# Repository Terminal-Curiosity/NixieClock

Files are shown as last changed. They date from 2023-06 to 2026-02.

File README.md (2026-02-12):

# Nixie Clock

A retro-style digital clock built with nixie tubes and an ESP32 microcontroller, custom built to fit into the scrap metal remains of an X-ray Tube.

## Features

- **Nixie Tube Display**: Classic nixie tube display showing time in HHMM format
- **2x Custom PCBs**: Designed to retrofit the X-ray Tube shell
- **RGB LED Backlight**: RGB LEDs behind each tube for added colour and dazzle
- **ESP32 Microcontroller**: Powered by an ESP32 Wroom32 microcontroller dev board
- **WiFi Time sync**: Daily time sync using wifi NTP to correct against clock drift and daylight savings
- **Cathode Protection**: daily nixie tube conditioning to prevent cathode poisoning

## Block Diagram

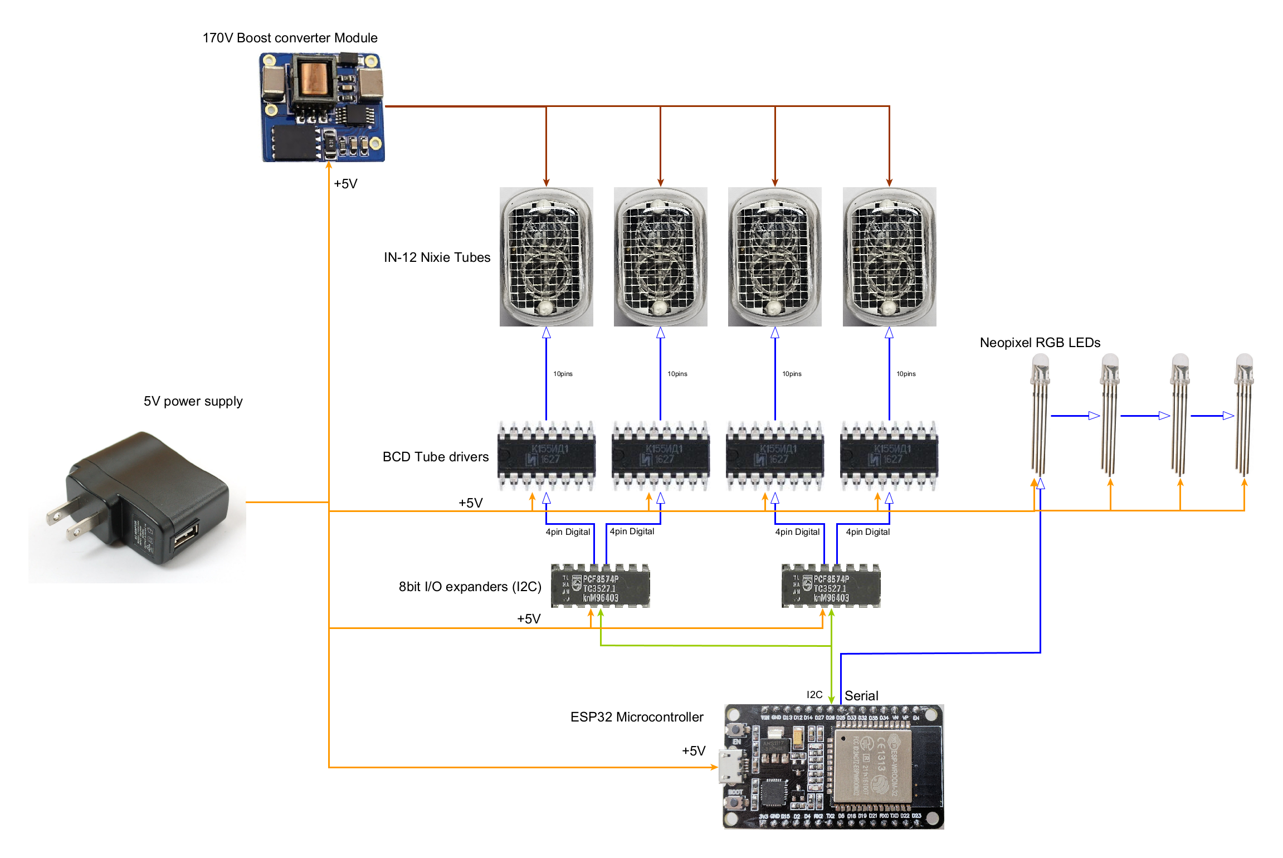
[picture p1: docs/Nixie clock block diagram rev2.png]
Nixie Clock Block Diagram


## Hardware

### Main Components

- **Microcontroller**: ESP32 Wroom32 DevKit-C
- **Nixie Tubes**: 4x IN-12 display
- **I/O Expansion**: 2x PCF8574 I2C I/O expanders
- **Decoders**: K155ID1 BCD-to-decimal decoders
- **Brightness Control**: Light Dependent Resistor (LDR)
- **Decoration LEDs**: 4x PL9823 RGB LEDs
- **High Voltage Supply**: NCH8200HV Nixie Power Booster Module

### Custom PCBs

The project includes Two custom PCB designs:

1. **NixieClock_ControlDaughterBoard**: Main control board with ESP32, HV Supply and LEDs
2. **NixieClock_NixieTubePanel**: Nixie tube display panel with decoder logic

### GPIO Pin Configuration

| Pin | Function |
|-----|---|
| 4 | SDA1 (I2C Bus 1) |
| 15  | SCL1 (I2C Bus 1) |
| 21  | SDA2 (I2C Bus 2) |
| 22  | SCL2 (I2C Bus 2) |
| 19  | INT2 (Interrupt, unused) |
| 32  | RGB LED (NeoPixel) |
| 23  | HV Enable (High Voltage supply) |
| 33  | LDR (Analog input) |

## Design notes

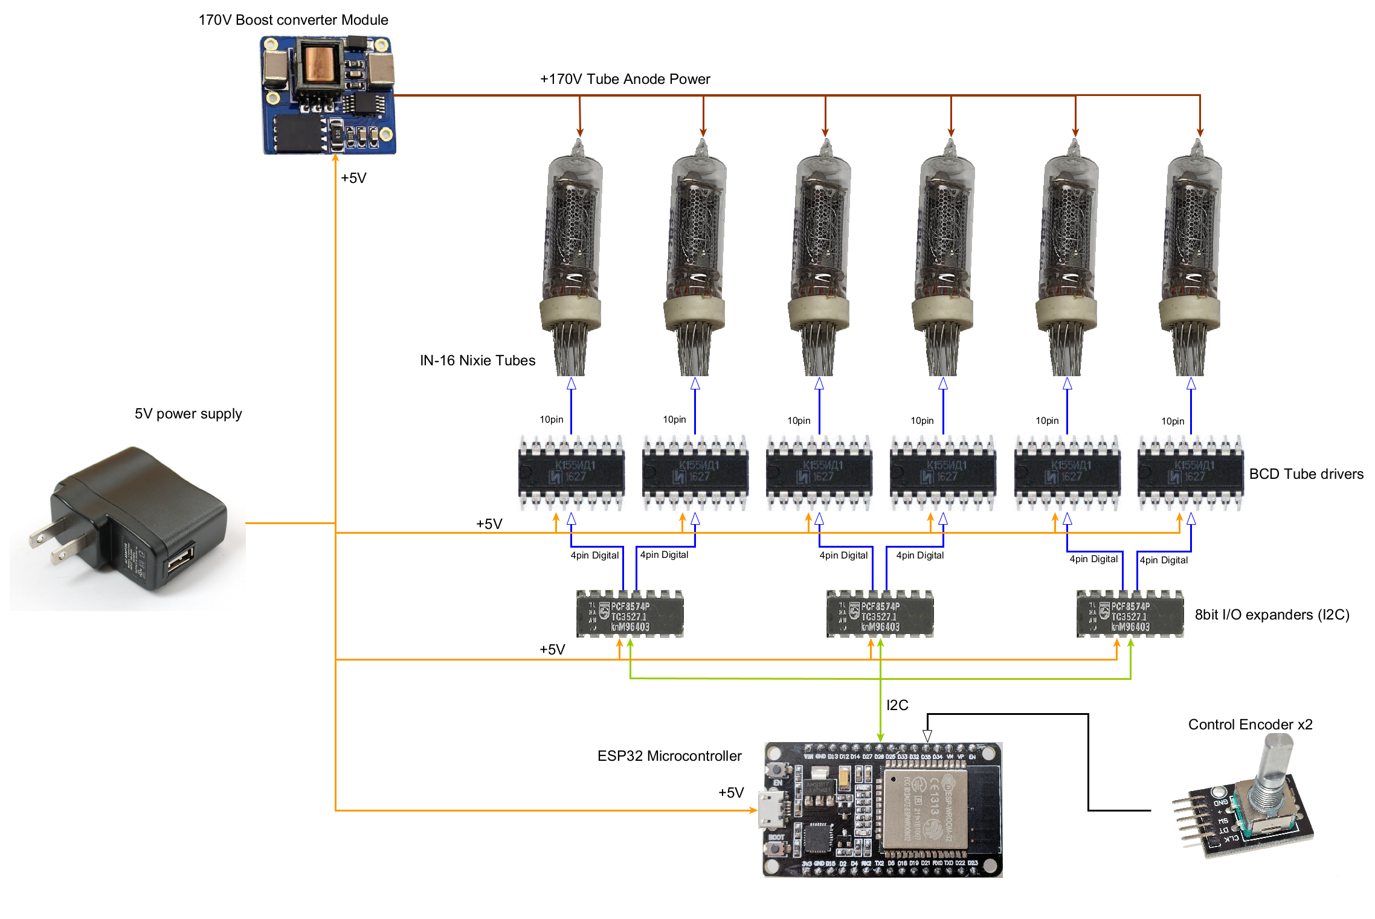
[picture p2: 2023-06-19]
docs/design/Nixie clock block diagram.png

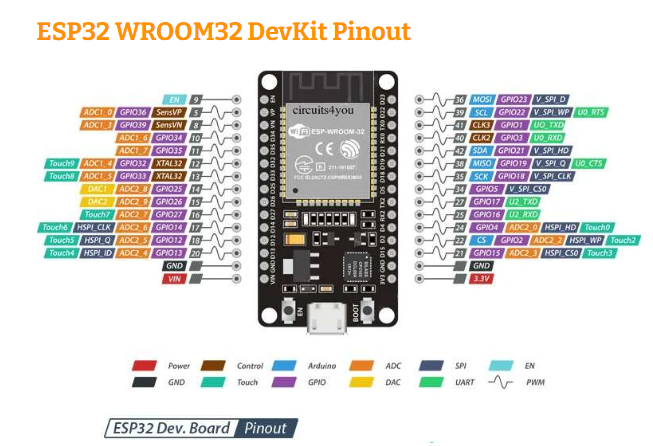
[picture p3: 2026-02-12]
docs/Datasheets/ESP32 pinout.png

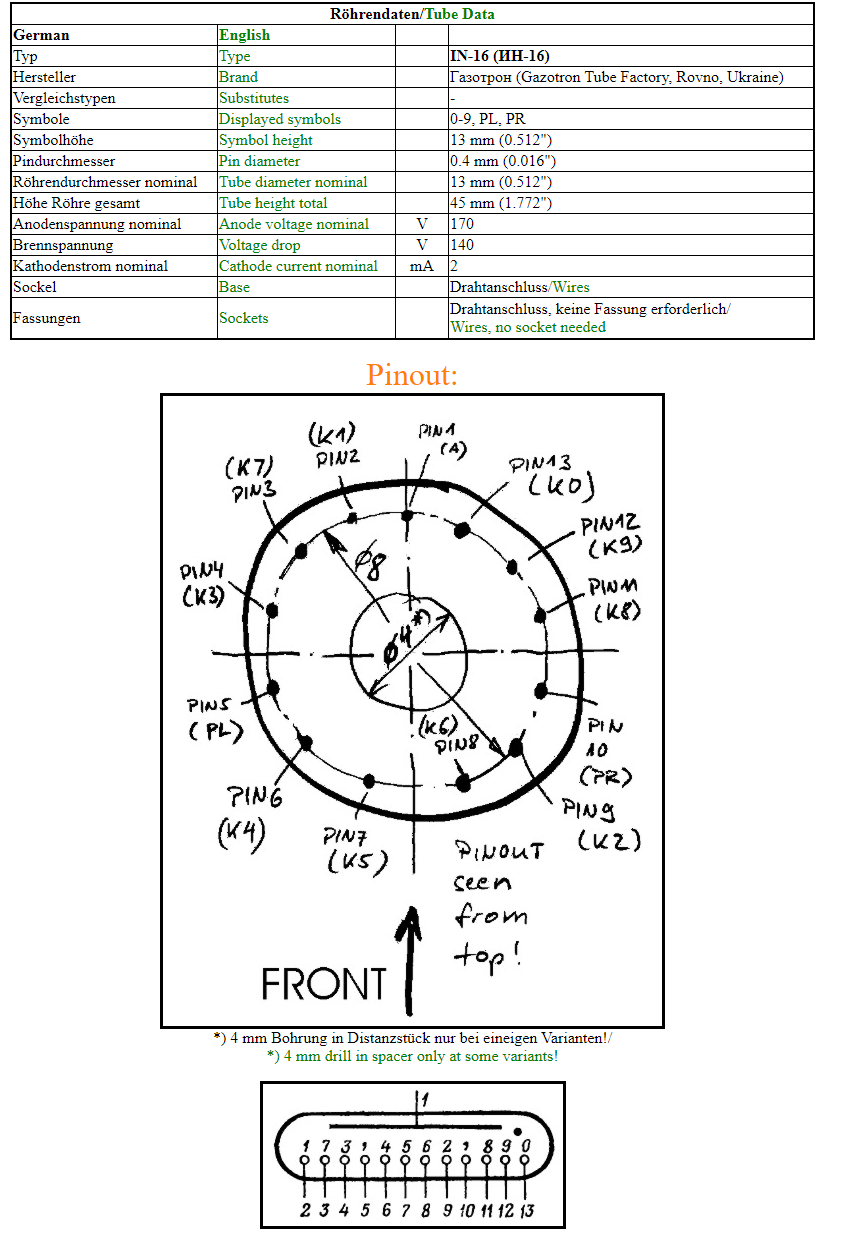
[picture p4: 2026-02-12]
docs/Datasheets/IN-16 Pinout and footprint.PNG

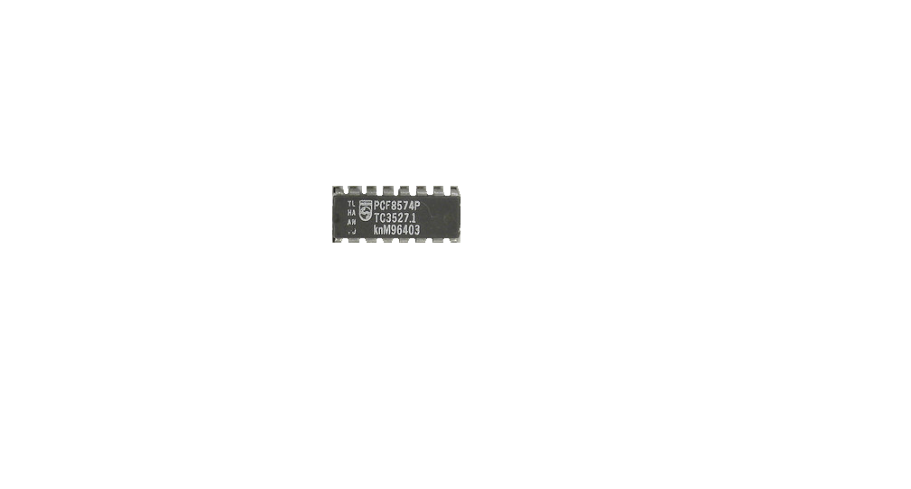
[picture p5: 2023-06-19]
docs/images/PCF8574 image.png

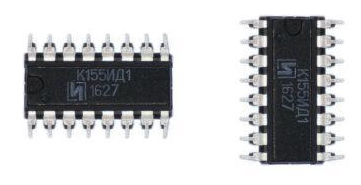
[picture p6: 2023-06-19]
docs/images/K155ND1 image.png

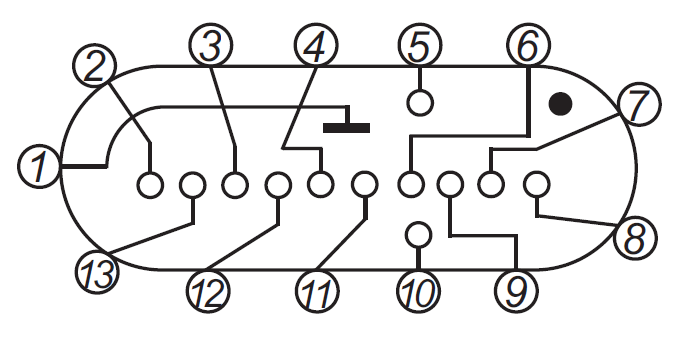
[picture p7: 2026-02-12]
docs/Datasheets/IN-16 Symbol.PNG

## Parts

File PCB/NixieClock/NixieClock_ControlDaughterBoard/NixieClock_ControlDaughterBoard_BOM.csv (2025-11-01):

Reference | Value | Description | Qty | Manufacturer | Manufacturer PN | Supplier
A1 | ASSY_NCH8200HV | NCH8200HV HV power supply 2.5-15VDC to 170V | 1 | Unknown | ASSY_NCH8200HV | Amazon
A2 | IC_ESP32-WROOM-32_DEVKIT | ESP32-WROOM-32 DEVKIT 30pin version | 1 | Espressif Systems | ESP32-WROOM-32_DEVKIT | Amazon
A3 | 4090 | ADAFRUIT USB C BREAKOUT BOARD | 1 | Adafruit | 4090 | Digikey
C1 | 470uF | CAP ALUM 470UF 20% 16V SMD | 1 | Nichicon | UWT1C471MNL1GS | Digikey
C2,C3 | 100nF | CAP CER 0.1UF 100V X7R 0805 | 2 | Samsung | CL21B104KCFNNNE | Digikey
D1,D2,D3,D4 | LED_IN-RGB-PL9823 | RGB LED Serial | 4 | Generic | PL9823 | Terminal Curiosity
F1 | 1.5A PTC | Resettable fuse, polymeric positive temperature coefficient | 1 | Littelfuse | NANOSMDC150F-2 | Digikey
J1,J2 | Conn_01x05 | CONN HEADER VERT 5POS 2.5MM | 2 | JST Sales America Inc. | B5B-XH-A | Digikey
J3,J4 | Conn_01x04 | CONN HDR 4POS 0.1 TIN PCB | 2 | Sullins Connector Solutions | PPTC041LFBN-RC | Digikey
Q1,Q2 | IRLML6244 | 6.3A Id, 20V Vds, 21mOhm Rds, N-Channel StrongIRFET Power MOSFET, SOT-23 | 2 | Infineon | IRLML6244TRPBF | Digikey
Q3 | IRLML6402 | -3.7A Id, -20V Vds, 65mOhm Rds, P-Channel HEXFET Power MOSFET, SOT-23 | 1 | Infineon | IRLML6402TRPBF | Digikey
R1,R2,R5,R6 | 4.7K | RES 4.7K OHM 5% 1/8W 0805 | 4 | Yageo | RC0805JR-074K7L | Digikey
R3,R9 | 470R | RES 470 OHM 1% 1/8W 0805 | 2 | Yageo | RC0805FR-07470RL | Digikey
R4,R7,R8,R15,R17 | 10k | RES 10K OHM 1% 1/8W 0805 | 5 | Yageo | RC0805FR-1310KL | Digikey
TP1 | 5V | PC TEST POINT | 1 | KOA Speer | RCUCTE | Digikey
TP2 | 3V3 | PC TEST POINT | 1 | KOA Speer | RCUCTE | Digikey
TP5,TP6 | 0V | PC TEST POINT | 2 | KOA Speer | RCUCTE | Digikey

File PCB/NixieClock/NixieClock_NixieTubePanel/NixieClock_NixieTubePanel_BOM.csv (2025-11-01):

Reference | Value | Description | Qty | Manufacturer | Manufacturer PN | Supplier
X1,X2,X3,X4,X5,X6 | 5230 | BATT CONTACT SOLID MULTIPLE SMD | 6 | Keystone Electronics | 122TR | Digikey
U5,U6 | PCF8574 | PCF8574 8BIT I2C PORT EXPANDER | 2 | Texas Instruments | PCF8574ADWR | Digikey
U1,U2,U3,U4 | K155ID1 | K155ID1 NIXIE TUBE DRIVER IC | 4 | Unknown | Unknown | eBay
R18 | 10K | Light Dependent Resistor 10K 150V | 1 | LDR Photoresistors | LDR07 | Unknown
R9,R10,R11,R16 | 18K | RES 18K OHM 5% 1/4W 1206 | 4 | YAGEO | RC1206JR-0718KL | Digikey
N1,N2,N3,N4 | TUBE_IN-12A_Nixie | IN-12A Nixie tube | 4 | Unknown | Unknown | eBay
J3,J4 | Conn_01x04_Pin | Generic connector, single row, 01x04, script generated | 2 | Wurth Elektronik | 61300411121 | Digikey
C5,C6,C7,C8,C9,C10 | 100nF | CAP CER 0.1UF 100V X7R 0805 | 6 | Samsung | CL21B104KCFNNNE | Digikey

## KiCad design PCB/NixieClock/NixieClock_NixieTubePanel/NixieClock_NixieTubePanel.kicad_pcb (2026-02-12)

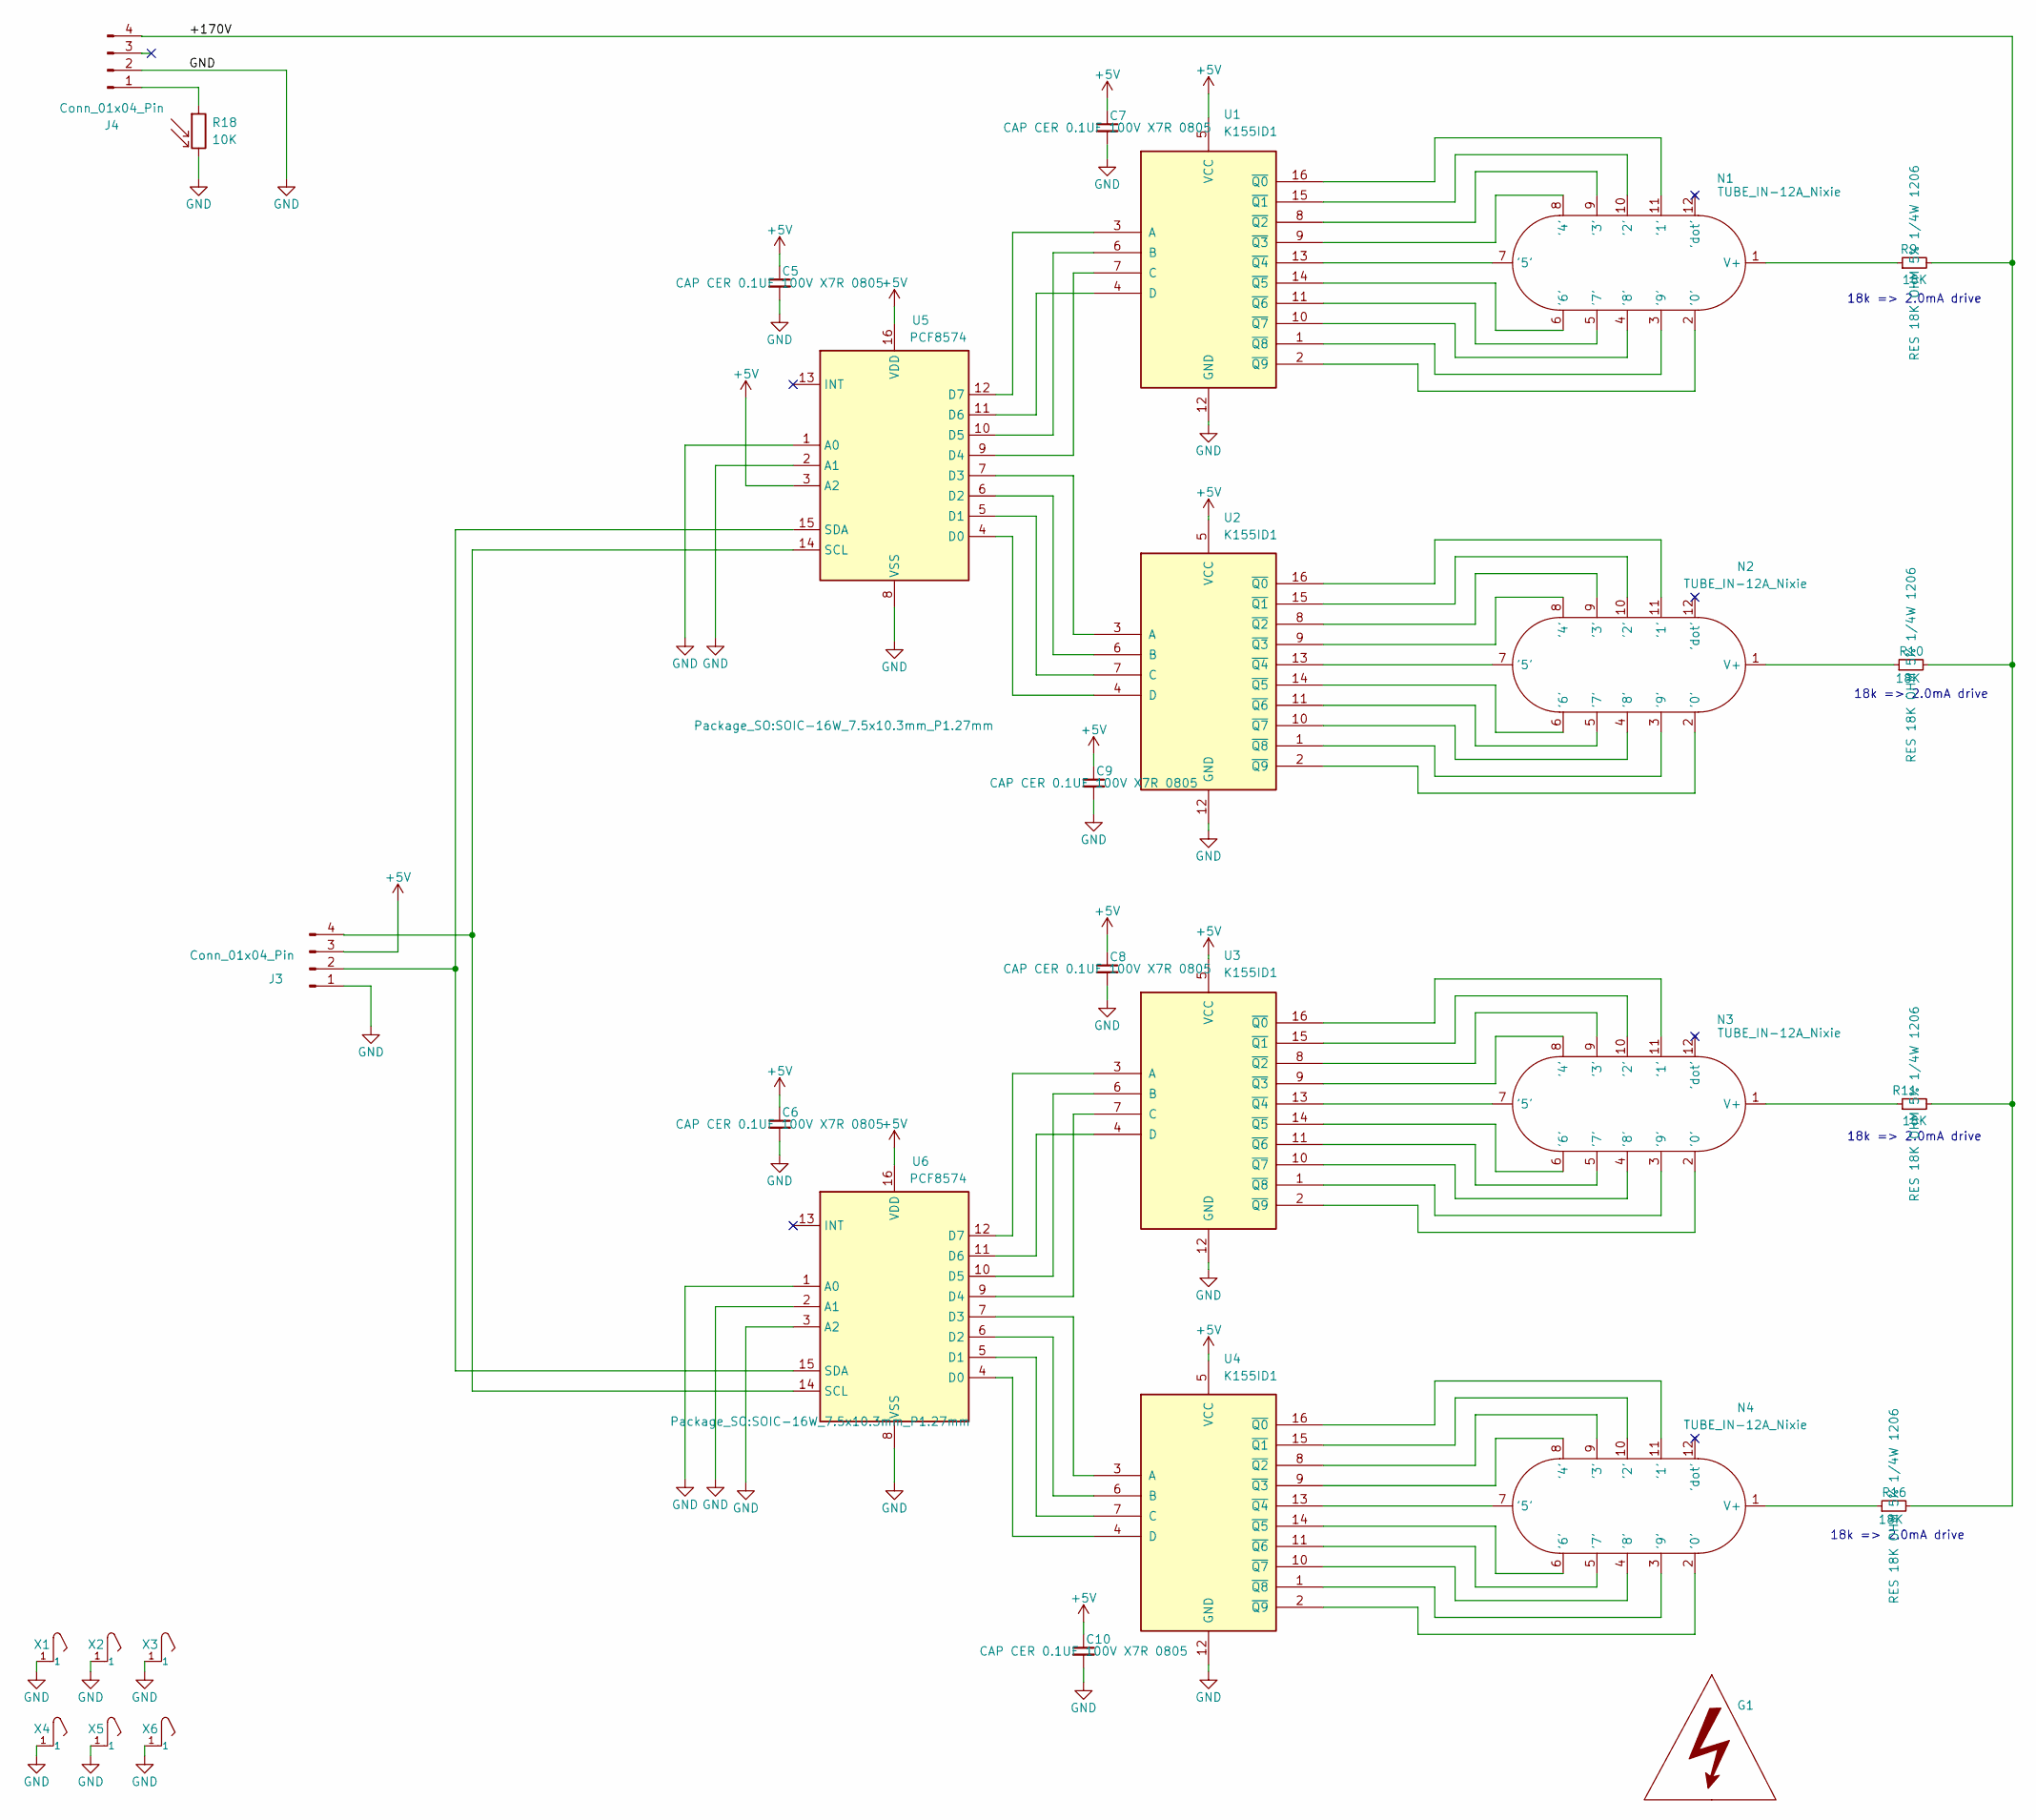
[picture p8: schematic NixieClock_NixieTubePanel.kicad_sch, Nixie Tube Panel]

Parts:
C5, C6, C7, C8, C9, C10: 100nF; C_0805_2012Metric_Pad1.18x1.45mm_HandSolder; Manufacturer PN CL21B104KCFNNNE
G1: LABEL_HVWarning
J3, J4: Conn_01x04_Pin; PinHeader_1x04_P2.54mm_Vertical; Manufacturer PN 61300411121
N1, N2, N3, N4: TUBE_IN-12A_Nixie; in-12_nixie-tube-socket; Manufacturer PN Unknown
R9, R10, R11, R16: 18K; R_1206_3216Metric_Pad1.30x1.75mm_HandSolder; Manufacturer PN RC1206JR-0718KL
R18: 10K; R_LDR_5.1x4.3mm_P3.4mm_Vertical; Manufacturer PN LDR07
U1, U2, U3, U4: K155ID1; DIP-16_W7.62mm; Manufacturer PN Unknown
U5, U6: PCF8574; SOIC-16W_7.5x10.3mm_P1.27mm; Manufacturer PN PCF8574ADWR
X1, X2, X3, X4, X5, X6: 5230; CONN-Batt-Spring-SMD-3.5mmX3.5mm; Manufacturer PN 122TR

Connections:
+5V: C5.1, C6.1, C7.1, C8.1, C9.1, C10.1, J3.3, U1.5 (VCC), U2.5 (VCC), U3.5 (VCC), U4.5 (VCC), U5.3 (A2), U5.16 (VDD), U6.16 (VDD)
/+170V: J4.4, R9.2, R10.2, R11.2, R16.2
GND: C5.2, C6.2, C7.2, C8.2, C9.2, C10.2, J3.1, J4.2, R18.2, U1.12 (GND), U2.12 (GND), U3.12 (GND), U4.12 (GND), U5.1 (A0), U5.2 (A1), U5.8 (VSS), U6.1 (A0), U6.2 (A1), U6.3 (A2), U6.8 (VSS), X1.1, X2.1, X3.1, X4.1, X5.1, X6.1
unnamed: J3.2, U5.15 (SDA), U6.15 (SDA)
unnamed: J3.4, U5.14 (SCL), U6.14 (SCL)
unnamed: J4.1, R18.1
unnamed: N1.2 ('0'), U1.2 (~Q9)
unnamed: N1.11 ('1'), U1.16 (~Q0)
unnamed: N1.10 ('2'), U1.15 (~Q1)
unnamed: N1.9 ('3'), U1.8 (~Q2)
unnamed: N1.8 ('4'), U1.9 (~Q3)
unnamed: N1.7 ('5'), U1.13 (~Q4)
unnamed: N1.6 ('6'), U1.14 (~Q5)
unnamed: N1.5 ('7'), U1.11 (~Q6)
unnamed: N1.4 ('8'), U1.10 (~Q7)
unnamed: N1.3 ('9'), U1.1 (~Q8)
unnamed: N1.1 (V+), R9.1
unnamed: N2.2 ('0'), U2.2 (~Q9)
unnamed: N2.11 ('1'), U2.16 (~Q0)
unnamed: N2.10 ('2'), U2.15 (~Q1)
unnamed: N2.9 ('3'), U2.8 (~Q2)
unnamed: N2.8 ('4'), U2.9 (~Q3)
unnamed: N2.7 ('5'), U2.13 (~Q4)
unnamed: N2.6 ('6'), U2.14 (~Q5)
unnamed: N2.5 ('7'), U2.11 (~Q6)
unnamed: N2.4 ('8'), U2.10 (~Q7)
unnamed: N2.3 ('9'), U2.1 (~Q8)
unnamed: N2.1 (V+), R10.1
unnamed: N3.2 ('0'), U3.2 (~Q9)
unnamed: N3.11 ('1'), U3.16 (~Q0)
unnamed: N3.10 ('2'), U3.15 (~Q1)
unnamed: N3.9 ('3'), U3.8 (~Q2)
unnamed: N3.8 ('4'), U3.9 (~Q3)
unnamed: N3.7 ('5'), U3.13 (~Q4)
unnamed: N3.6 ('6'), U3.14 (~Q5)
unnamed: N3.5 ('7'), U3.11 (~Q6)
unnamed: N3.4 ('8'), U3.10 (~Q7)
unnamed: N3.3 ('9'), U3.1 (~Q8)
unnamed: N3.1 (V+), R11.1
unnamed: N4.2 ('0'), U4.2 (~Q9)
unnamed: N4.11 ('1'), U4.16 (~Q0)
unnamed: N4.10 ('2'), U4.15 (~Q1)
unnamed: N4.9 ('3'), U4.8 (~Q2)
unnamed: N4.8 ('4'), U4.9 (~Q3)
unnamed: N4.7 ('5'), U4.13 (~Q4)
unnamed: N4.6 ('6'), U4.14 (~Q5)
unnamed: N4.5 ('7'), U4.11 (~Q6)
unnamed: N4.4 ('8'), U4.10 (~Q7)
unnamed: N4.3 ('9'), U4.1 (~Q8)
unnamed: N4.1 (V+), R16.1
unnamed: U1.3 (A), U5.12 (D7)
unnamed: U1.6 (B), U5.10 (D5)
unnamed: U1.7 (C), U5.9 (D4)
unnamed: U1.4 (D), U5.11 (D6)
unnamed: U2.3 (A), U5.7 (D3)
unnamed: U2.6 (B), U5.6 (D2)
unnamed: U2.7 (C), U5.5 (D1)
unnamed: U2.4 (D), U5.4 (D0)
unnamed: U3.3 (A), U6.12 (D7)
unnamed: U3.6 (B), U6.10 (D5)
unnamed: U3.7 (C), U6.9 (D4)
unnamed: U3.4 (D), U6.11 (D6)
unnamed: U4.3 (A), U6.7 (D3)
unnamed: U4.6 (B), U6.6 (D2)
unnamed: U4.7 (C), U6.5 (D1)
unnamed: U4.4 (D), U6.4 (D0)

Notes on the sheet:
18k => 2.0mA drive

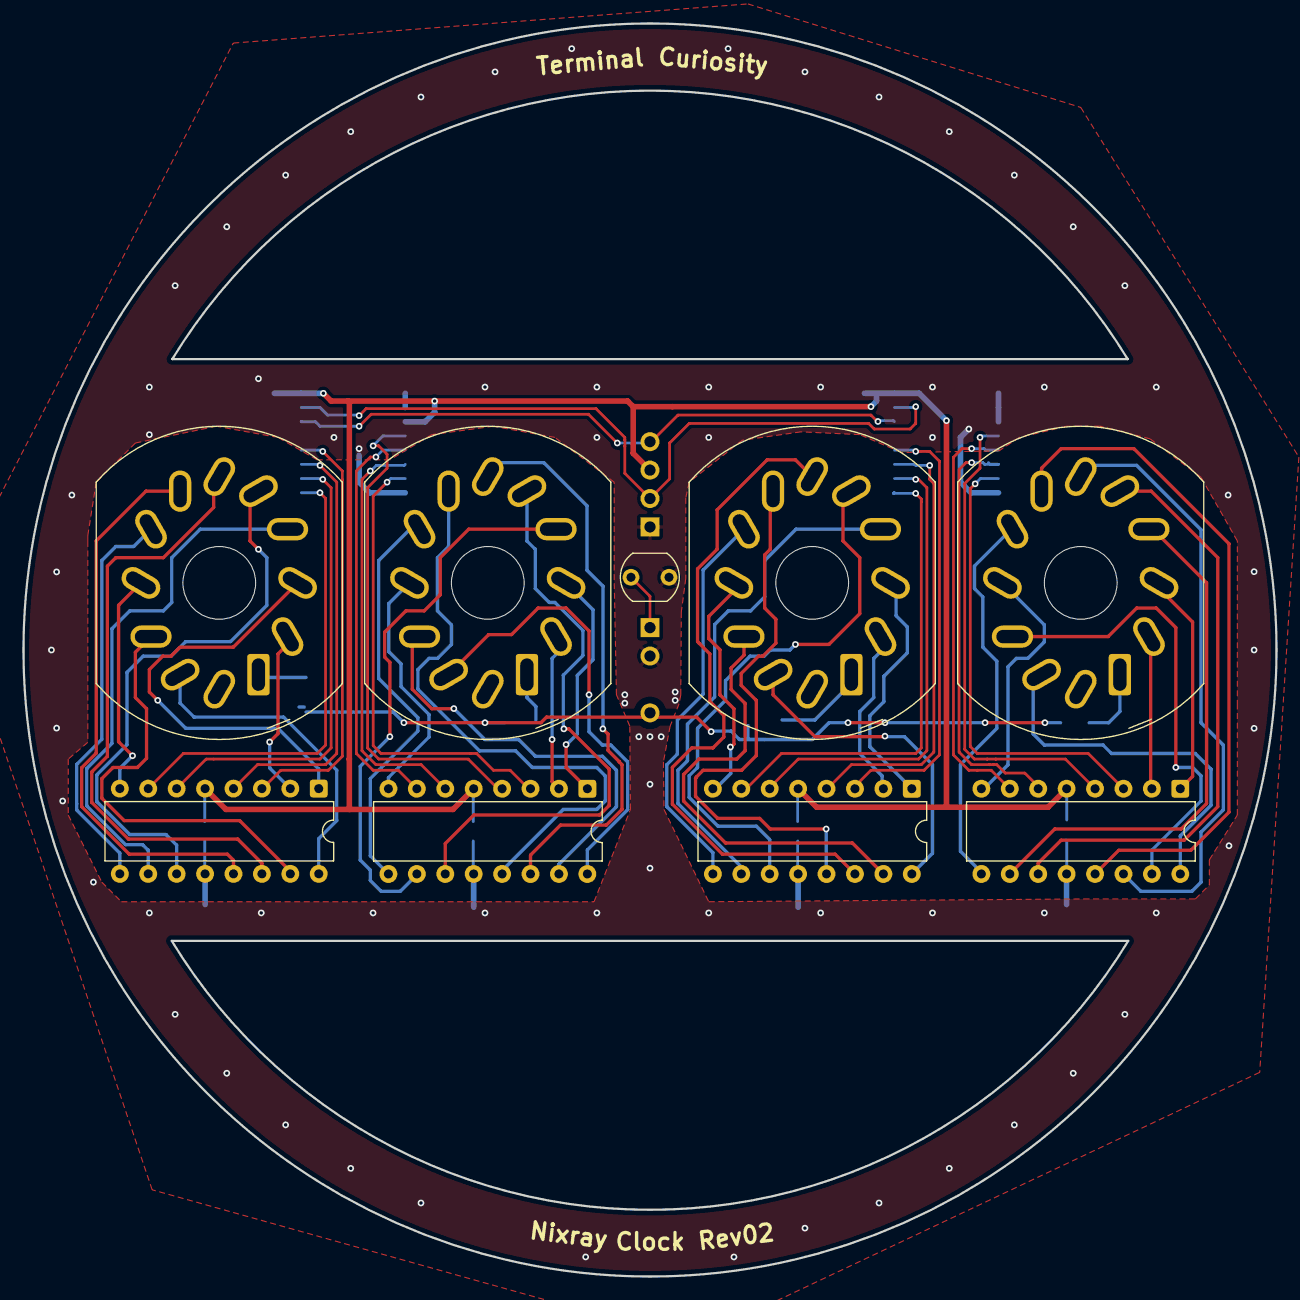
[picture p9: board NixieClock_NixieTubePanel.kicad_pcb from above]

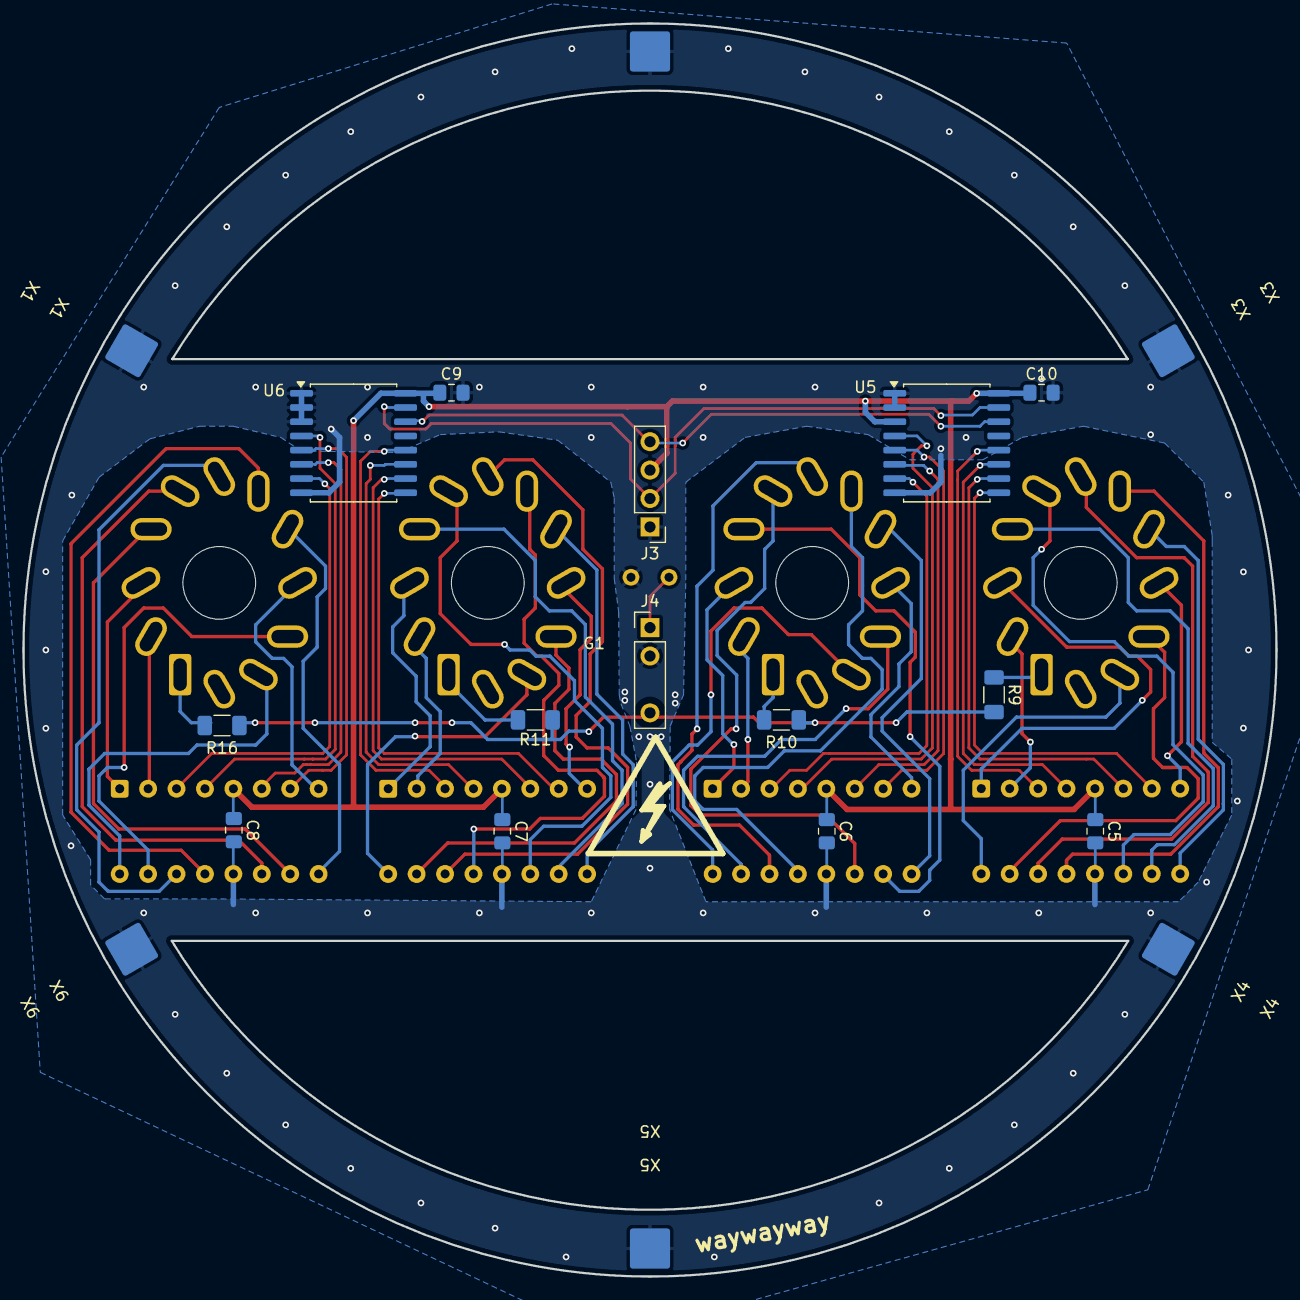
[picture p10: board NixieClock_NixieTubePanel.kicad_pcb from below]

Board: 2 copper layers, 112.0 x 112.0 mm, 30 parts (21 on the bottom side), 66 nets.

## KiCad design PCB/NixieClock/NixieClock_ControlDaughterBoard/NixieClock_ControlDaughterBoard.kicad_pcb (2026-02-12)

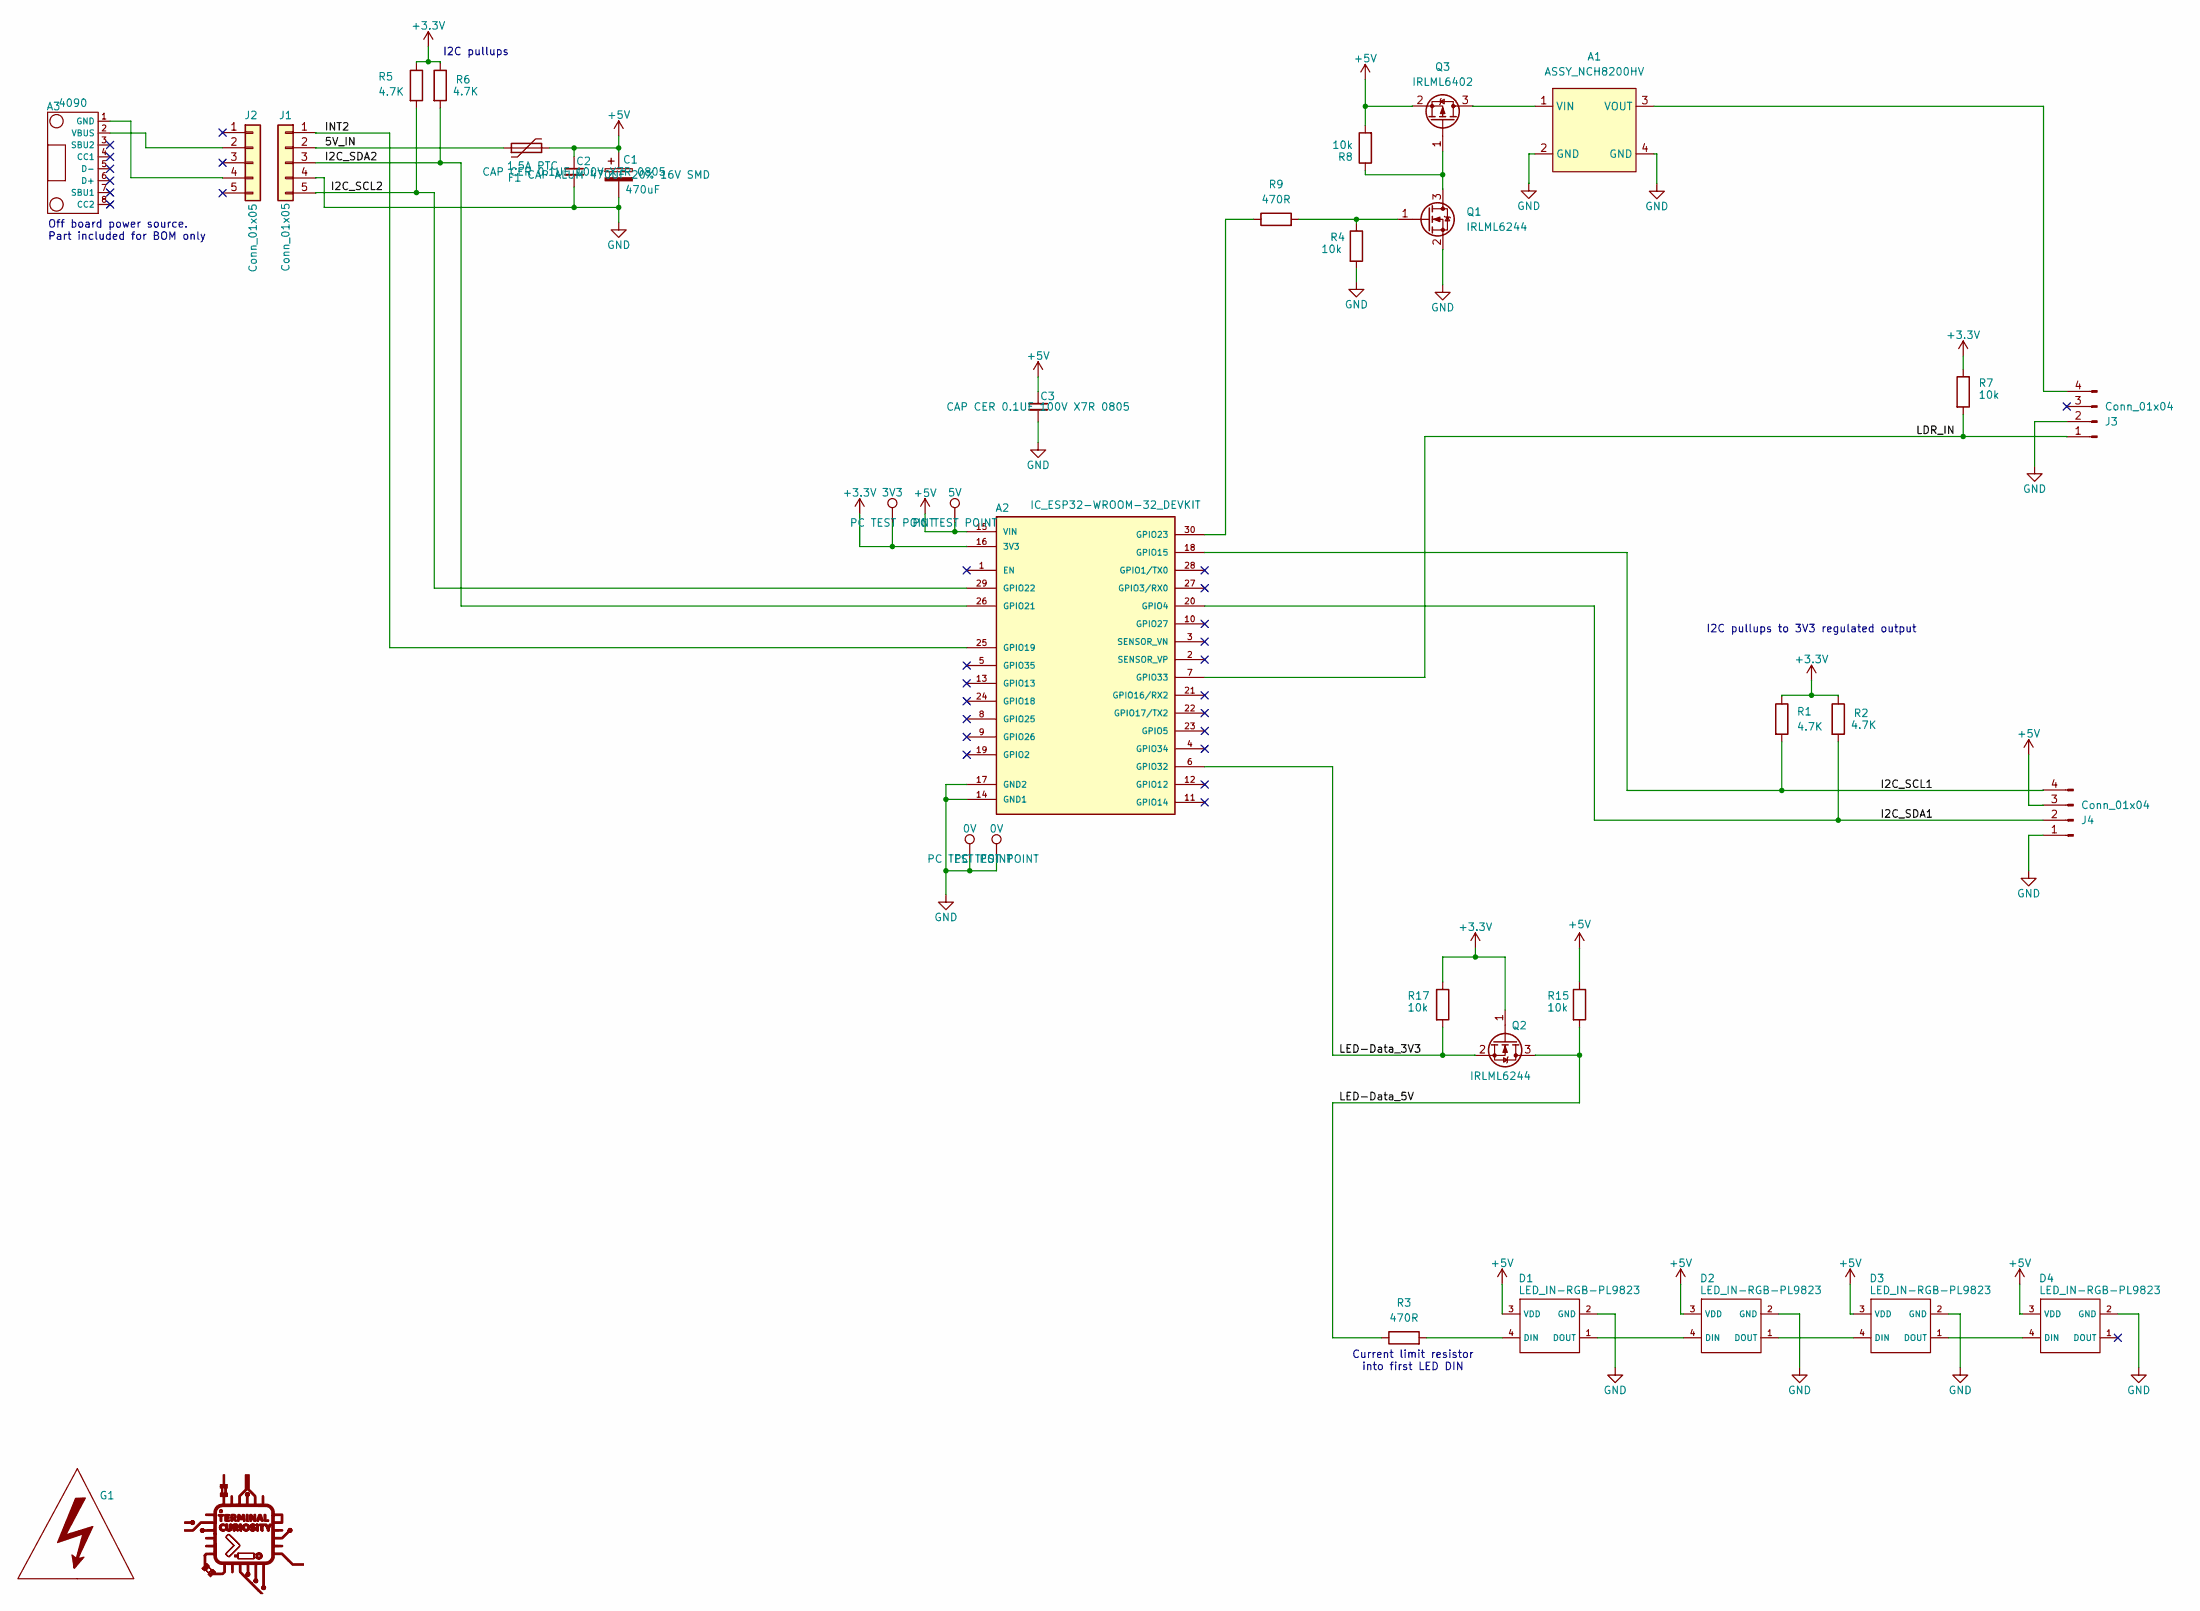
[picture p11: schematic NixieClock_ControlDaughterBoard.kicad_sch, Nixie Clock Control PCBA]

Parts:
A1: ASSY_NCH8200HV; NCH8200HV; Manufacturer PN ASSY_NCH8200HV
A2: IC_ESP32-WROOM-32_DEVKIT; MODULE_ESP32-DEVKITC-32D; Manufacturer PN ESP32-WROOM-32_DEVKIT
A3: 4090; Manufacturer PN 4090
C1: 470uF; CP_Elec_8x10; Manufacturer PN UWT1C471MNL1GS
C2, C3: 100nF; C_0805_2012Metric_Pad1.18x1.45mm_HandSolder; Manufacturer PN CL21B104KCFNNNE
D1, D2, D3, D4: LED_IN-RGB-PL9823; LED_D5.0mm-4_RGB; Manufacturer PN PL9823
F1: 1.5A PTC; R_1206_3216Metric_Pad1.30x1.75mm_HandSolder; Manufacturer PN NANOSMDC150F-2
G1: LABEL_HVWarning
G2: LOGO; LABEL_TerminalCuriosity_25.0x25.0mm
J1, J2: Conn_01x05; JST_XH_B5B-XH-A_1x05_P2.50mm_Vertical; Manufacturer PN B5B-XH-A
J3, J4: Conn_01x04; PinSocket_1x04_P2.54mm_Vertical; Manufacturer PN PPTC041LFBN-RC
Q1, Q2: IRLML6244; SOT-23; Manufacturer PN IRLML6244TRPBF
Q3: IRLML6402; SOT-23; Manufacturer PN IRLML6402TRPBF
R1, R2, R5, R6: 4.7K; R_0805_2012Metric_Pad1.20x1.40mm_HandSolder; Manufacturer PN RC0805JR-074K7L
R3, R9: 470R; R_0805_2012Metric_Pad1.20x1.40mm_HandSolder; Manufacturer PN RC0805FR-07470RL
R4, R7, R8, R15, R17: 10k; R_0805_2012Metric_Pad1.20x1.40mm_HandSolder; Manufacturer PN RC0805FR-1310KL
TP1: 5V; TestPoint_Pad_2.0x2.0mm; Manufacturer PN RCUCTE
TP2: 3V3; TestPoint_Pad_2.0x2.0mm; Manufacturer PN RCUCTE
TP5, TP6: 0V; TestPoint_Pad_2.0x2.0mm; Manufacturer PN RCUCTE

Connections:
+3.3V: A2.16 (3V3), Q2.1 (G), R1.1, R2.1, R5.1, R6.1, R7.1, R17.1, TP2.1
+5V: A2.15 (VIN), C1.1, C2.1, C3.1, D1.3 (VDD), D2.3 (VDD), D3.3 (VDD), D4.3 (VDD), F1.2, J4.3, Q3.2 (S), R8.2, R15.1, TP1.1
/5V_IN: F1.1, J1.2
/I2C_SCL1: A2.18 (GPIO15), J4.4, R1.2
/I2C_SCL2: A2.29 (GPIO22), J1.5, R5.2
/I2C_SDA1: A2.20 (GPIO4), J4.2, R2.2
/I2C_SDA2: A2.26 (GPIO21), J1.3, R6.2
/INT2: A2.25 (GPIO19), J1.1
/LDR_IN: A2.7 (GPIO33), J3.1, R7.2
/LED-Data_3V3: A2.6 (GPIO32), Q2.2 (S), R17.2
/LED-Data_5V: Q2.3 (D), R3.1, R15.2
GND: A1.2 (GND), A1.4 (GND), A2.14 (GND1), A2.17 (GND2), C1.2, C2.2, C3.2, D1.2 (GND), D2.2 (GND), D3.2 (GND), D4.2 (GND), J1.4, J3.2, J4.1, Q1.2 (S), R4.2, TP5.1, TP6.1
unnamed: A1.1 (VIN), Q3.3 (D)
unnamed: A1.3 (VOUT), J3.4
unnamed: A2.30 (GPIO23), R9.1
unnamed: A3.1 (GND), J2.4
unnamed: A3.2 (VBUS), J2.2
unnamed: D1.4 (DIN), R3.2
unnamed: D1.1 (DOUT), D2.4 (DIN)
unnamed: D2.1 (DOUT), D3.4 (DIN)
unnamed: D3.1 (DOUT), D4.4 (DIN)
unnamed: Q1.3 (D), Q3.1 (G), R8.1
unnamed: Q1.1 (G), R4.1, R9.2

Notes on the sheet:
I2C pullups
Current limit resistor into first LED DIN
I2C pullups to 3V3 regulated output
Off board power source. Part included for BOM only

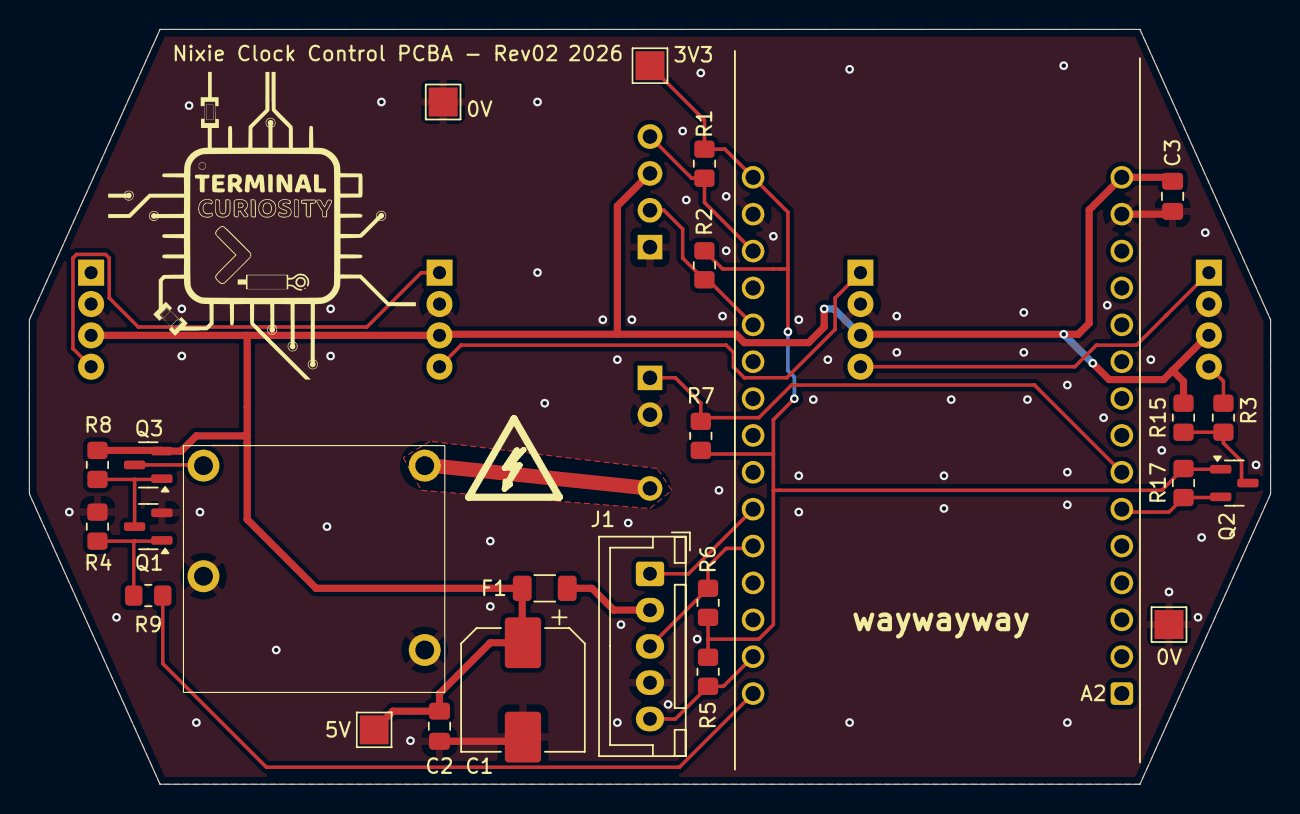
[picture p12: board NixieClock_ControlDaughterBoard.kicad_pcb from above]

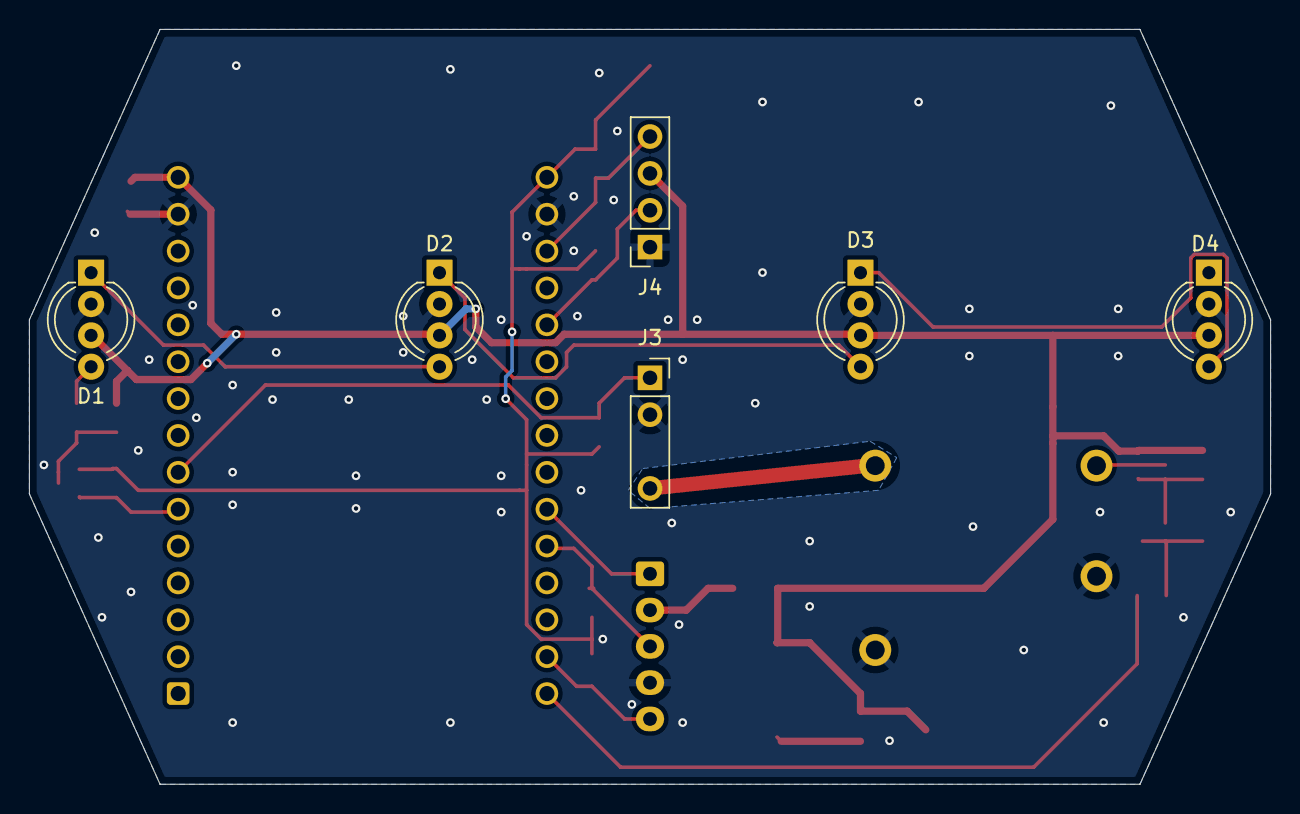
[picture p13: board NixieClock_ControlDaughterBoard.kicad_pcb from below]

Board: 2 copper layers, 85.5 x 52.0 mm, 33 parts (6 on the bottom side), 21 nets.

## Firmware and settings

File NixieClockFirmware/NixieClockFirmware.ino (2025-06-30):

#include <Wire.h>

//define digital pins communicating to driver chip
#define pin1 = 19
#define pin2 = 1
#define pin3 = 3
#define pin4 = 23

#define led_pin = 4

#define IO1_addr 0x24 //assign the i2c expander addresses
const int IO2_addr = 0x22;
const int IO3_addr = 0x20;

#define SDA_pin 21
#define SCL_pin 22

const int digitCode[] = {8,1,10,11,2,12,4,0,9,3}; //working using non inverted outputs
//const int digitCode[] = {0b0111,0b1011,0b1100,0b1101,0b0101,0b1110,0b0100,0b0011,0b0110,0b1111};

void digitCycle(int);
void writeDigit(int);
void write1byte(byte, byte);

void setup() {
  // put your setup code here, to run once:
  Wire.begin(SDA_pin,SCL_pin); // initialise IO bit expander 1 I2C channel
  Wire.setClock(100000);
  //Serial.begin(115200);
  //pinMode(SDA_pin, INPUT_PULLUP); //use internal pullups on the I2c pins instead of external hardware resistors
  //pinMode(SCL_pin, INPUT_PULLUP);
  
  pinMode(pin1, OUTPUT); // set all digital pins to output
  pinMode(pin2, OUTPUT);
  pinMode(pin3, OUTPUT);
  pinMode(pin4, OUTPUT);
  pinMode(led_pin, OUTPUT);
  
  digitalWrite(pin1,LOW); // initialise all digital pins low
  digitalWrite(pin2,LOW);
  digitalWrite(pin3,LOW);
  digitalWrite(pin4,LOW);

  Wire.beginTransmission(IO3_addr); // turn off all GPIO pins on port expanders by writing all "1"
  Wire.write(0xFF);
  Wire.endTransmission();
  delay(5);
  Wire.beginTransmission(IO2_addr);
  Wire.write(0xFF);
  Wire.endTransmission();
  delay(5);
  Wire.beginTransmission(IO1_addr);
  Wire.write(0xFF);
  Wire.endTransmission();
  
}

void loop() {

  while(1)
    { 
      digitCycle(1000);
      digitCycle(100);
      

     
      
      
    }
  
}

void digitCycle(int delayms)
{
  for(int i=0; i<10; i++) //loop through all possible 4 bit states rapidly to show that we have reached end of the loop
  {
    writeDigit(i);
    write1byte(IO1_addr,i);
    delay(delayms); //wait 0.5sec before next transition
  }
}

void writeDigit(int digit)
{
    int address = digitCode[digit];
    digitalWrite(pin1,bitRead(address,0)); //read 0th bit of i, set it high on pin1
    digitalWrite(pin2,bitRead(address,1));
    digitalWrite(pin3,bitRead(address,2));
    digitalWrite(pin4,bitRead(address,3));
}

void write1byte(byte address, byte digit)
{
    byte sendVal = digitCode[digit] + (digit<<4);  
    Serial.println(sendVal,BIN);
    Wire.beginTransmission(address);
    //Wire.write(0x01);
    Wire.write(sendVal);
    Wire.endTransmission();
    byte error = Wire.endTransmission();
    Serial.print("Sent to 0x");
    Serial.print(address, HEX);
    Serial.print(" — Error: ");
    Serial.println(error);
    delay(5);
}

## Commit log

2023-06-19 Commit Nixie Clock files
    [NixieClock.kicad_pcb, NixieClock.kicad_sch, Nixie_Pair.kicad_sch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]
2025-06-11 nixie panel PCB layout progress
    laid out tube 1 with top and bottom traces. added GND polygon on both sides, with exception zone around tube 1. tubes 2-4 to be laid out with top and bottom traces
    [NixieClock.kicad_pcb, NixieClock.stl, NixieClock_NixieTubePanel.kicad_pcb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]
2025-06-11 Nixie driver board - single board
    Capture state of files for nixie driver board before splitting into two separate boards.
    delete temporary files that open only when kicad is open and are not needed in git.
    [NixieClock.kicad_sch]
2025-06-13 complete tube 2 wiring
    complete trace layout for tube 2 on top and bot side
    [NixieClock_NixieTubePanel.kicad_pcb]
2025-06-13 tube 2 checkpoint
    tubes 1 and 2 have been routed using top/bot traces. saving checkpoint before rerouting tube 3 the same
    [NixieClock_NixieTubePanel.kicad_pcb]
2025-06-13 Tube 3 wiring complete
    Tube 3 wiring top/bot complete. tube 4 started
    [NixieClock_NixieTubePanel.kicad_pcb]
2025-06-13 Tidied U1 and U3 connections
    adjust pin ordering on U1 and U3 in schematic so they would connect to the PCF chips neater on the PCB without needing vias
    [NixieClock_NixieTubePanel.kicad_pcb, NixieClock_NixieTubePanel.kicad_sch]
2025-06-13 change driver 3 ground trace to back side
    rerouted some traces so that driver chip 3 ground trace can run on the back instead of the front, which looks neater and matches the other 3 chips
    [NixieClock_NixieTubePanel.kicad_pcb]
2025-06-19 Route tube 4
    Finished routing tube 4 top and bottom traces
    [NixieClock_NixieTubePanel.kicad_pcb]
2025-06-19 add Polygon pour + stitching vias
    Add polygon ground pour to top and bottom. add stitching vias all around board for improved layer connection. add polygon keepout zones to keep ground plane away from HV components
    [NixieClock_NixieTubePanel.kicad_pcb]
2025-06-30 mid-DRC review
    mid review checkpoint. errors require reloading footprints from library, which might break a lot of things. This checkpoint captures last good state
    [NixieClock_NixieTubePanel.kicad_pcb]
2025-06-30 DRC cleared
    0 DRC errors
    [NixieClock_NixieTubePanel.kicad_pcb, NixieClock_NixieTubePanel.kicad_sch]
2025-06-30 Tidied messy polygon generation around R18
    Polygon bridge from top to bottom was narrowed but then it created plane discontinuities so this widened it again slightly. DRC zero
    [NixieClock_NixieTubePanel.kicad_pcb]
2025-06-30 Tidied +170V trace slightly
    some unnecessary diagonal lines were removed
    [NixieClock_NixieTubePanel.kicad_pcb]
2025-06-30 increase HV clearance on U3:8 trace
    moved trace further from LV signals
    [NixieClock_NixieTubePanel.kicad_pcb]
2025-06-30 Move Monoboard files to Archive
    Monoboard files to be split into two separate PCBs because the monoboard PCB shape is too small. files moved to archive for reference but not for development
    [NixieClock.kicad_pcb, NixieClock.kicad_sch, NixieClock.stl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]
2025-06-30 Removed dead files
    remove dead files
    [Nixie_Pair.kicad_sch, tube_pair.kicad_sch, untitled.kicad_sch]
2025-07-14 Fix SMD components missing B.Paste
    change B.Paste clearance to 0 to return paste on SMD components.
    Paste not necessary because hand soldering, but its good practice
    [NixieClock_NixieTubePanel.kicad_pcb]
2025-07-20 Layout WIP
    lock in locations of mech-critical components (LEDs, connectors) and initial layout of non mech-critical components.
    next step: define trace rules and start wiring layout
    [NixieClock_ControlDaughterBoard.kicad_pcb, NixieClock_ControlDaughterBoard.kicad_sch]
2025-07-20 Remove unconnected pin3 on J4
    pin3 was not electrically connected. removing it creates better creepage between HV pin 4 and LV pin 2
    [NixieClock_NixieTubePanel.kicad_pcb]
2025-07-20 Layout WIP
    layout half completed.
    +5V net class added to SCH so it has thicker traces on PCB
    [NixieClock_ControlDaughterBoard.kicad_pcb, NixieClock_ControlDaughterBoard.kicad_sch]
2025-07-21 Add current limit resistor to N-MOS base
    needed to limit current into N-MOS during switching on. improves EMI and protects gate/esp driver from excessive current.
    [NixieClock_ControlDaughterBoard.kicad_sch]
2025-07-21 layout draft1 complete
    completed all pcb routing and polygon pour.
    Changed LED footprints to wide pins. previously they had 0.085mm clearance between pads, which is too tight to manufacture. wide pins have 0.36mm min (14mil) which is above PCBway suggested 6mil.
    Removed all DRC errors.
    Some warnings exist for ESP32 silkscreen beyond board border, but this is ok for the assembly overall
    [NixieClock_ControlDaughterBoard.kicad_pcb]
2025-07-21 remove text note to self
    text note no longer needed
    [NixieClock_ControlDaughterBoard.kicad_sch]
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2025-07-22 Increase height by 2mm
    increase short side height from 50mm to 52mm to match the exact length of the ESP32 devkit PCBA.
    without this, the ESP would extend past this panel PCB by 1mm on both sides and would be visible from behind the clock
    [NixieClock_NixieTubePanel.kicad_pcb]
2025-07-22 Add dimensions to square section
    add dimensions for readability
    [NixieClock_NixieTubePanel.kicad_pcb]
2025-07-22 PCB layout 2 complete
    layout 1 was incorrect as the connectors and LEDs were not located in the right place to correctly mate with the tube panel PCBA. When connectors and LEDs were moved, all the traces became scrambled. it was necessary to re-wire the entire board.
    ESP32 pins were also remapped to improve ease of wiring
    [NixieClock_ControlDaughterBoard.kicad_pcb, NixieClock_ControlDaughterBoard.kicad_sch]
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2025-07-29 I2C pin remap based on breadboard tests
    tested I2C pin mappings on breadboard and found that using GPIO2 caused the board to get stuck in boot mode. remapped to adjacent pin GPIO4 for safety.
    [NixieClock_ControlDaughterBoard.kicad_pcb, NixieClock_ControlDaughterBoard.kicad_sch]
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2025-08-29 Increase clearance to LED holes in tube centres
    moved traces to provide more creepage/clearance to 6mm holes in the centre of the nixie tube sockets and prevent HV issues to LEDs that will be positioned there
    [NixieClock_NixieTubePanel.kicad_pcb]
2025-08-29 Increased solder mask clearance to 0.3mm around tube socket centre holes
    to increase HV clearance area and safety at the component level wrt centre hole (and any LEDs inside said hole)
    [NixieClock_NixieTubePanel.kicad_pcb]
2025-08-30 tidy labels and adjacent vias
    aligned silkscreen labels and moved nearby vias to not conflict
    [NixieClock_NixieTubePanel.kicad_pcb]
2025-08-30 Tidy component details and add BOM
    fill missing supplier/mfr info on resistors and caps. export BOM
    [NixieClock_NixieTubePanel.kicad_sch, NixieClock_NixieTubePanel_BOM.csv]
2025-08-30 Fill component details and export BOM
    filled missing component information, exported BOM
    [NixieClock_ControlDaughterBoard.csv, NixieClock_ControlDaughterBoard.kicad_sch]
2025-08-30 Rename bom file to [project]_BOM
    Rename bom file to [project]_BOM as generated by SCH file
    [NixieClock_ControlDaughterBoard_BOM.csv]
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2025-09-01 Change anode resistors from 0805 to 1206 for increased power headroom
    changed resistors and adjusted traces to suit.
    0805 resistors have Pmax 0.125W. if the PSU drifts up to 180-185V, it may exceed this power rating.
    1206 doubles the headroom
    [NixieClock_NixieTubePanel.kicad_pcb, NixieClock_NixieTubePanel.kicad_sch]
2025-09-01 Correct part details from 0805 to 1206 missed in previous commit
    also correct BOM
    [NixieClock_NixieTubePanel.kicad_sch, NixieClock_NixieTubePanel_BOM.csv]
2025-09-01 Add 2025 to silkscreen
    add current year to project silkscreen. regenerate gerbers to suit
    [NixieClock_ControlDaughterBoard.kicad_pcb]
2026-01-01 decoupling caps 0603 -> 0805 for easier soldering
    prototype feedback found that decoupling caps can be 0805 sized and easier to hand solder. 0603 is not required
    [NixieClock_NixieTubePanel.kicad_pcb, NixieClock_NixieTubePanel.kicad_sch]
2026-01-01 swap pins 1,2 on LEDs
    LED pin layout was mistakenly swapped. discovered on Rev01 prototype. swapped pins in the SCH and PCB files. updated assembly to Rev02
    [NixieClock_ControlDaughterBoard.kicad_pcb, NixieClock_ControlDaughterBoard.kicad_sch]
2026-01-03 fixed power in pin (1->2)
    J2 5V pin was mistakenly wired to pin 1 instead of pin 2 (like on the control board connector J1)
    [NixieClock_ControlDaughterBoard.kicad_sch]
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2026-01-08 Restructure the project directories and files
    [NixieClock.kicad_pcb, NixieClock.kicad_sch, NixieClock.stl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]
2026-01-08 Restore datasheets and docs
    restoring files that were mistakenly removed
    [IN-12 footprint hole locations.xlsx, Tube footprint pads coordinates.xlsx]
2026-01-31 consolidate project datasheets and images
    [IN-12 footprint hole locations.xlsx, Tube footprint pads coordinates.xlsx]
2026-01-31 tidy project structure
    [IN-12 footprint hole locations.xlsx, Tube footprint pads coordinates.xlsx]
2026-01-31 One LED did not update to the correct footprint
    the pins were still reversed from the original error. fixed that and regenerated polygon pour
    [NixieClock_ControlDaughterBoard.kicad_pcb]
2026-01-31 changed folder name "_PCB" -> "PCB" and deleted duplicate PCB files.
    project structure contained _PCB folder and PCB folder, both containing duplicate kicad files. PCB folder appeared to be junk and outdated files so was deleted and _PCB folder was renamed to PCB
    [NixieClock.kicad_pcb, NixieClock.kicad_sch, NixieClock_ControlDaughterBoard.kicad_pcb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]
2026-02-12 component manufacturer details were incorrect
    deleted "MANUFACTURER" and "MANUFACTURER P/N" fields. now using "Manufacturer" "Manufacturer PN" consistently across project
    [NixieClock_NixieTubePanel.kicad_sch]
